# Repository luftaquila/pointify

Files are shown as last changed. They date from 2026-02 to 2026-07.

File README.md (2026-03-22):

# Pointify

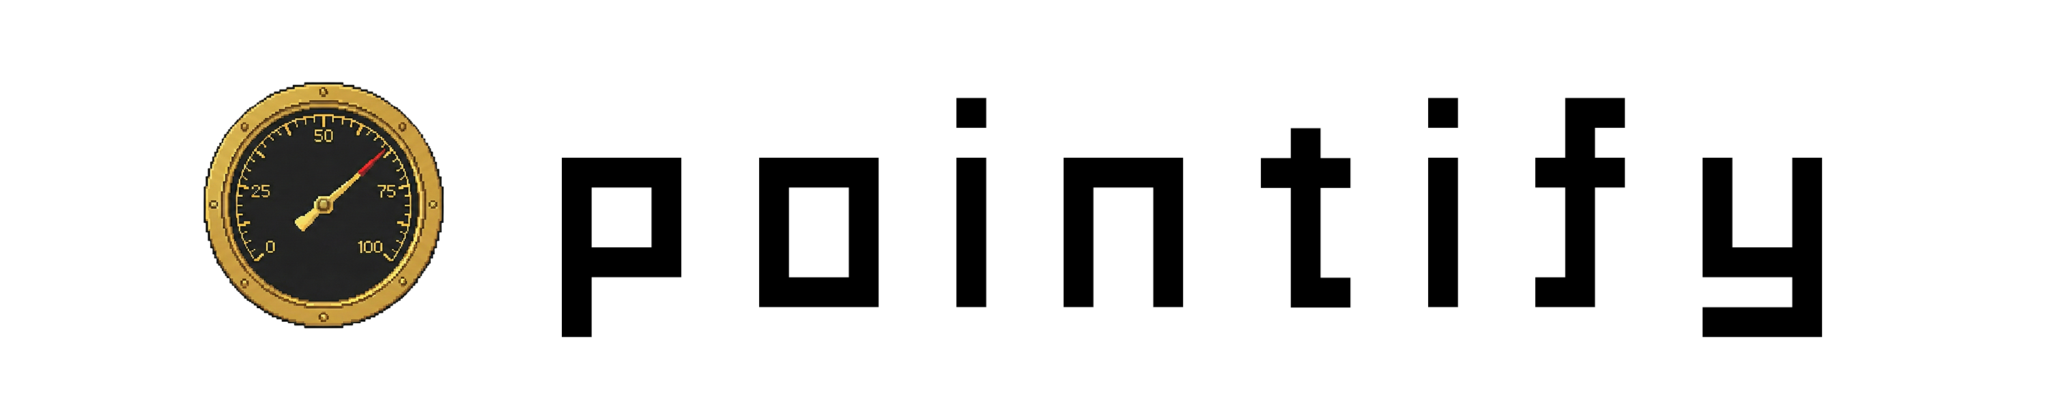
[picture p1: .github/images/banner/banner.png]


DIY retro analog gauge meters that display system metrics in real time, including Claude usage stats!

<table>
  <tr>
    <td>
      
    </td>
    <td>
      <video src="https://github.com/user-attachments/assets/7dd133b8-86af-4e1a-b1fe-1c4ecdfecce1" controls></video>
    </td>
  </tr>
</table>

## Usage

Pointify Desktop runs on macOS, Windows, and Linux, driving up to 8 gauges with customizable metrics.

Its software gauges work without the device, but watching real needles twitch is way better. So go build one!

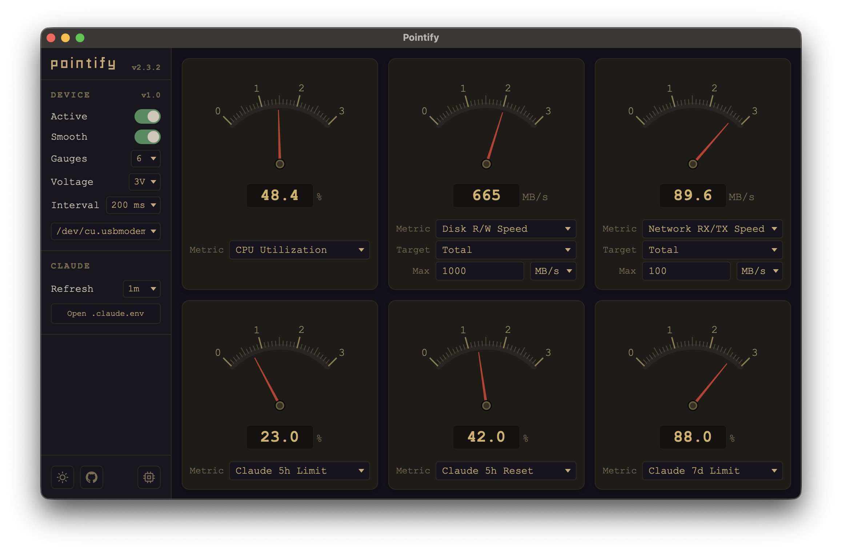
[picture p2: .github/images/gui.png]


1. Install Pointify Desktop and open it.
    * **macOS / Linux (Homebrew)**
      ```bash
      brew tap luftaquila/pointify https://github.com/luftaquila/pointify
      brew install --cask pointify # macOS
      brew install pointify        # Linux
      ```
    * **Windows (Manual)**: Download from the [latest release](https://github.com/luftaquila/pointify/releases/latest).
1. Connect your Pointify to the computer and set up gauges to your preference.

<details>

<summary>Full list of supported metrics</summary>

- 🕹️ Hardware
  - CPU
    - Utilization
    - Temperature
    - Clock Frequency
    - Power Consumption
  - GPU
    - Utilization
    - Temperature
    - Clock Frequency
    - Power Consumption
    - VRAM Usage
  - Memory
    - RAM and Swap Usage
  - Network
    - RX, TX and RX/TX Speed
  - Disk
    - Usage
    - Read, Write and R/W Speed
- **🤖 Claude Usage Stats**
  - Usage Limits
    - 5h session limit and reset time
    - Weekly limit and reset time
  - Claude Code stats
    - Today's total tokens
    - Today's input, output and I/O tokens
    - Today's cache read and write tokens
    - Today's cost ($)

</details>

> [!NOTE]
> Some metrics have platform/hardware limitations.
> * **CPU Temperature and Power**: Not available on Windows.
> * **GPU metrics**: Not supported on AMD graphics cards.
> * **GPU VRAM Usage**: Not available on Apple Silicon.

### Optional setup

To fetch Claude usage limits (5h session and weekly), Pointify needs your browser credentials.

Claude Code stats are collected from local logs and do not require credentials.

> [!NOTE]
> Credentials are stored locally and only used to fetch usage data directly from Claude. No information is sent to any third-party server.
> See the `get_claude_usage` function in [lib.rs](https://github.com/luftaquila/pointify/blob/v2/gui/src-tauri/src/lib.rs) for details.

<details>

<summary>Firefox</summary>

1. Open Firefox and visit `https://claude.ai`. Log in if you haven't already.
1. Open Developer Tools (F12).
1. Go to the `Storage` tab.
1. On the left sidebar, click `Cookies` - `https://claude.ai`.
1. Locate the `cf_clearance`, `lastActiveOrg`, and `sessionKey` values.
1. Click the `Open .claude.env` button on the desktop app and paste the corresponding values.

</details>

<details>

<summary>Chrome</summary>

1. Open Chrome and visit `https://claude.ai`. Log in if you haven't already.
1. Open Developer Tools (F12).
1. Go to the `Application` tab.
1. On the left sidebar, click `Storage` - `Cookies` - `https://claude.ai`.
1. Locate the `cf_clearance`, `lastActiveOrg`, and `sessionKey` values.
1. Click the `Open .claude.env` button on the desktop app and paste the corresponding values.

</details>

## Do It Yourself!

Pointify is fully open-source and open-hardware. Build your own device at home!

### 1. Build PCB

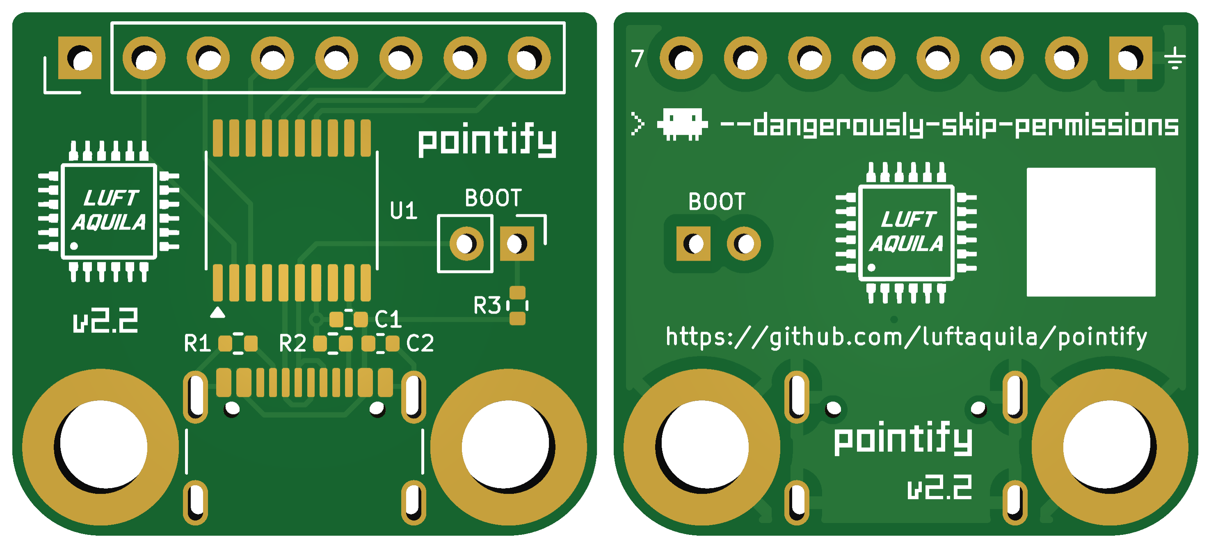
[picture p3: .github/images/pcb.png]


1. Download `pointify-hardware.zip` from the [latest release](https://github.com/luftaquila/pointify/releases/latest) and unzip.
1. Gerber, BOM, and CPL files are in the `pcb/` directory. Use them to place a PCB assembly order from manufacturers such as JLCPCB.

### 2. Upload Firmware

If your board is fresh and the MCU has never been flashed, it will always boot into USB bootloader mode.

1. Connect your board to the computer.
1. Open Pointify Desktop and click the chip icon at the bottom of the sidebar.

`CURRENT` version will show as `Bootloader`. Click the `Update Firmware` button to flash it.

> [!NOTE]
> If your computer is running Windows and `CURRENT` shows as `N/A`, it means the CH372 driver is missing.
> Press the `Shift` key and the button will change to `Update Firmware (force)`.
> The force install process will automatically detect and install the missing driver.
> Alternatively, you can install the driver manually from [here](https://www.wch-ic.com/downloads/CH372DRV_EXE.html).

### 3. 3D-Print Housing and Assembly

#### Prerequisites

* 6x M2*8mm bolts
* 91C4 3V DC analog voltmeters, as many as you need
* Some wires and soldering skills
* 4x anti-slip pads with radius < 10mm

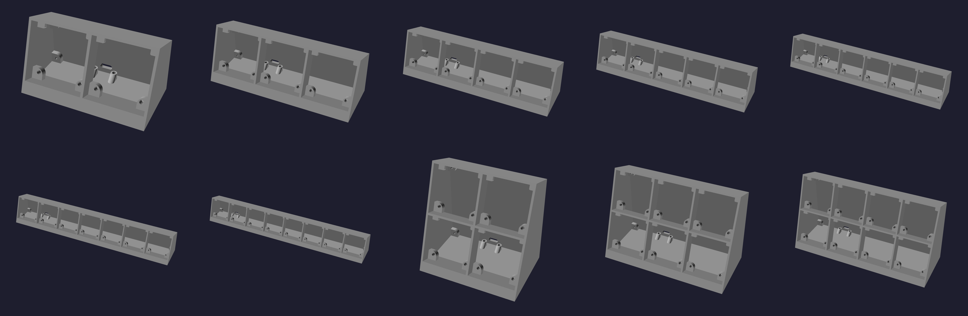
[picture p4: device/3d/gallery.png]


1. Download `pointify-hardware.zip` from the [latest release](https://github.com/luftaquila/pointify/releases/latest) and unzip.
1. 3D-print the STL files you need from the `3d/` directory.
1. Install the gauges into the housing.
1. Connect all negative terminals (near the 0V scale) of the gauge to the GND header on the PCB.
    * Daisy-chain them, since there's only one GND pad (marked ⏚).
1. Connect each positive terminal (near the 3V scale) to PWM port #1~8 on the PCB.
    * The pad right next to the GND is PWM1.
    * Solder directly to the washer that comes with the gauge, or crimp a ring terminal onto the wire. Crimping is easier to work with but you'll need a crimp tool and ring terminals.
1. Mount the PCB upside down onto the housing. The USB port faces downward.
1. Attach the back cover.

### 4. Customize Gauge Panel

Use the [Gauge Panel Generator](https://luftaquila.github.io/pointify/generator.html) to design and print your own gauge panel graphics.

Examples from the [device/gauge/example/](device/gauge/example) directory:

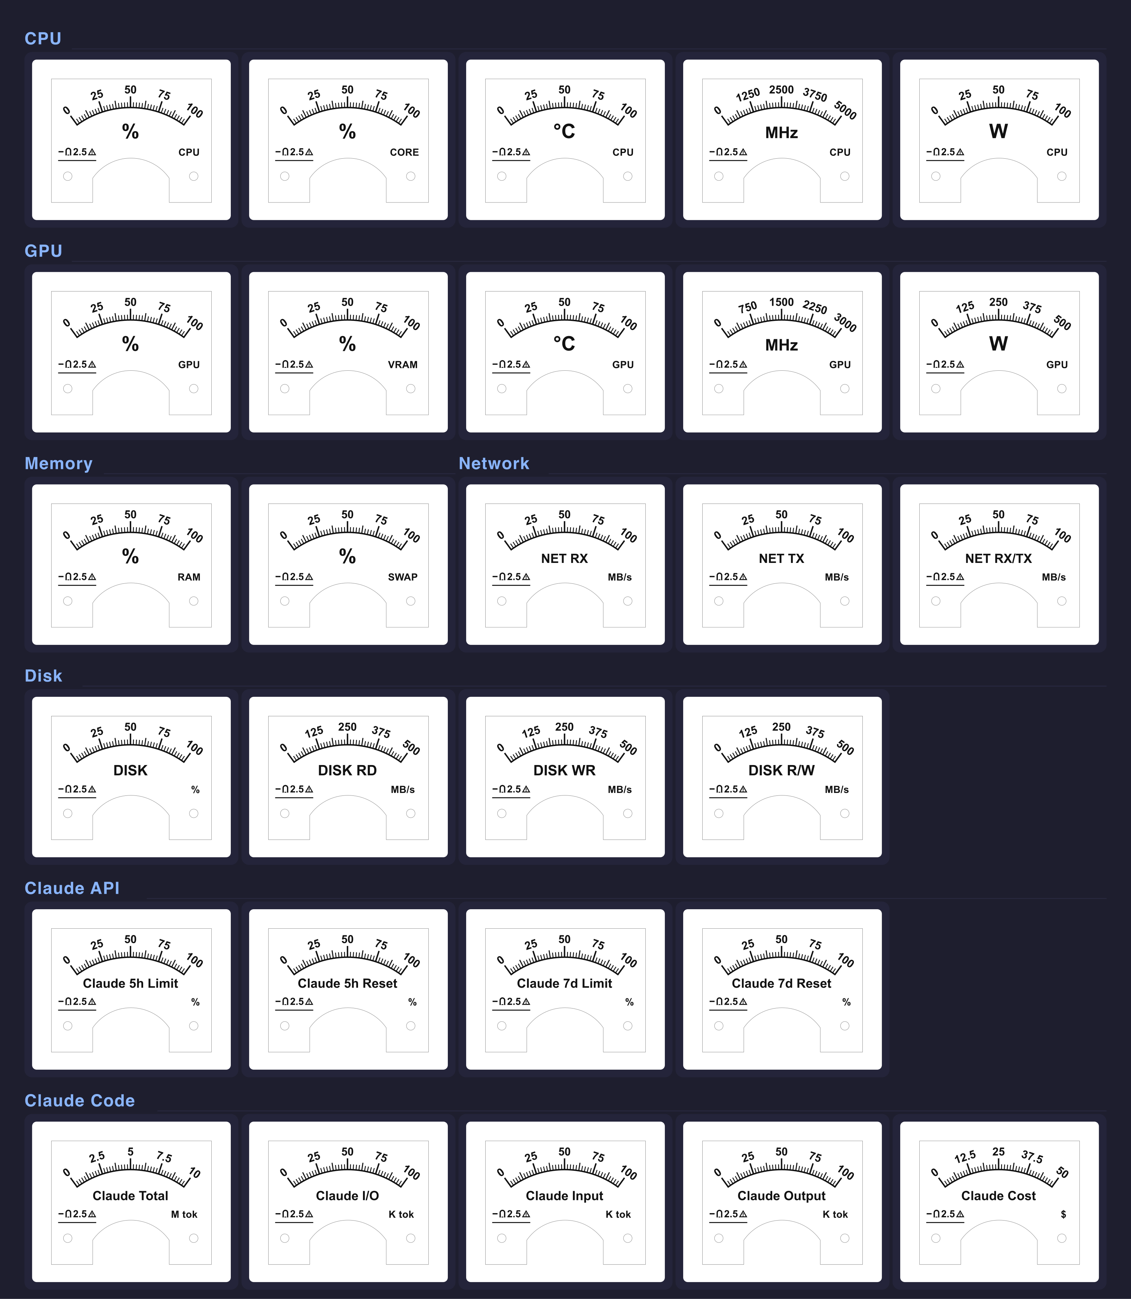
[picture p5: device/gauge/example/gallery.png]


## Development

<details>

<summary>Open</summary>

### Desktop App

Requires [Node.js](https://nodejs.org/en/download) and [Rust](https://rust-lang.org/tools/install/).

```bash
cd gui
npm install
npm run tauri dev       # development
npm run tauri build     # production
```

### Firmware

Requires [nightly Rust](https://rust-lang.github.io/rustup/concepts/channels.html#working-with-nightly-rust).

```bash
cargo install wchisp --git https://github.com/ch32-rs/wchisp

cd device/firmware
cargo build --release   # build only
cargo run --release     # build + flash
```

</details>

<hr>
<br>

<picture>
  <source media="(prefers-color-scheme: dark)" srcset="https://api.star-history.com/svg?repos=luftaquila/pointify&type=Date&theme=dark" />
  <source media="(prefers-color-scheme: light)" srcset="https://api.star-history.com/svg?repos=luftaquila/pointify&type=Date" />
  Star History Chart
</picture>

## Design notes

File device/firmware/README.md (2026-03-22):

# pointify-firmware

CH32X033F8P6 firmware built on [ch32-hal](https://github.com/ch32-rs/ch32-hal) with [Embassy](https://embassy.dev/) async runtime.

USB CDC ACM is implemented with raw PAC registers (`pac::usb::Usbd`) since ch32-hal has no USBFS HAL driver for this chip.

## Features

- USB CDC ACM device (VID=0x0200, PID=0x02DB)
- 8-channel PWM output (TIM1/TIM2/TIM3)
- Auto-detect 3.3V/5V supply via ADC internal reference
- Voltage-aware PWM scaling (3V gauges on 5V supply are scaled down)

## Prerequisites

```bash
cargo install probe-rs-tools
```

## Build & Flash

```bash
cargo run --release
```

Build only:

```bash
cargo build --release
```

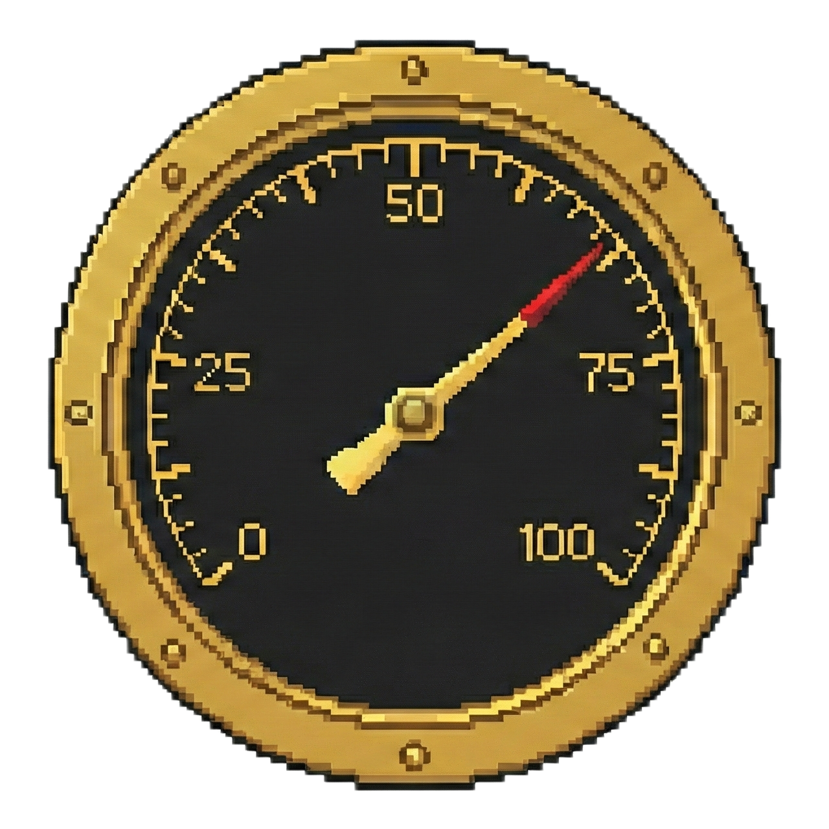
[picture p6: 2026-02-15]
.github/images/pointify.png

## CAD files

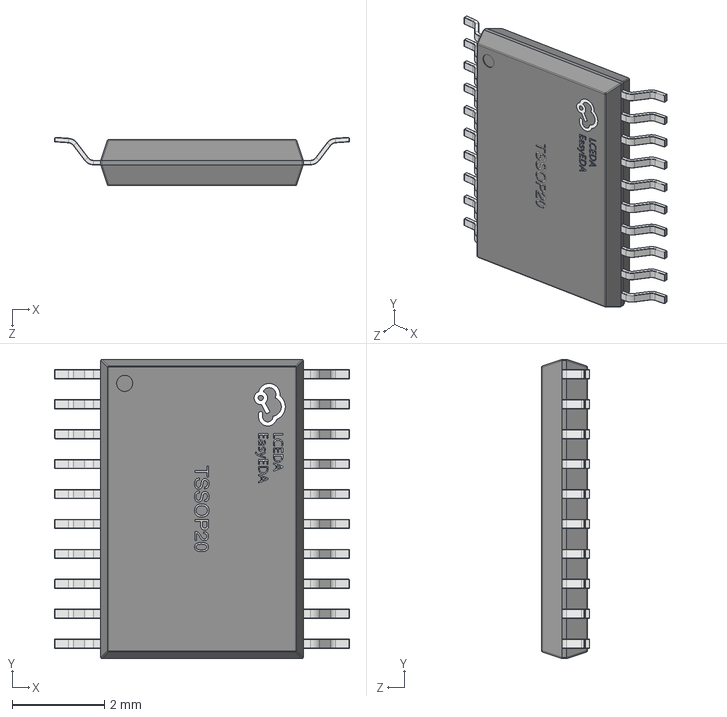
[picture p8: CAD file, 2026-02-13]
device/hardware/ch32x033f8p6/CH32X033F8P6.step
6.41 x 6.50 x 1.05 mm

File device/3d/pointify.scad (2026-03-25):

// ==========================================
// 1. Configuration & Parameters
// ==========================================
$fn = 100;

// [Grid Configuration]
num_cols = 3; // Columns (Width)
num_rows = 1; // Rows (Height)

// [Dimensions]
hole_sz = 46; // Unit hole size
hole_w = hole_sz - 1.0; // Hole width
hole_h = hole_sz - 0.5; // Hole height

gap = 2.0; // Wall thickness
margin_bot = 10; // Bottom margin
margin_top = 2.0; // Top margin

// [Calculated Dimensions]
// Total Width = (Cols * Hole) + Walls
face_w = (num_cols * hole_w) + ( (num_cols + 1) * gap);
// Total Height = (Rows * Hole) + Walls + Margins
face_h = margin_bot + (num_rows * hole_h) + ( (num_rows - 1) * gap) + margin_top;

// [View Settings]
explode_dist = 40; // 0 for assembly, >0 for exploded view
tolerance = 0.2;

// [Cover & Screw Settings]
cover_thickness = 3.0;
m2_tap_radius = 1.0; // Body hole (M2 Tap)
m2_clearance_radius = 1.5; // Cover hole (M2 Clearance)
m2_head_radius = 2.1; // Counterbore dia
m2_head_depth = 2.0; // Counterbore depth

// [Mounting Tab Settings]
tab_depth_len = 4;
tab_fillet_r = 4.0;

// [PCB & USB Settings]
pcb_hole_dist = 16.14;
pcb_dist_from_cover = 3.8;
pcb_boss_height = 5.0;
pcb_boss_dia = 5.0;
patch_nut_height = 2.0;

usb_w = 9.8;
usb_h = 3.8;
usb_r = usb_h / 2;

// [Geometry Definition]
tilt_angle = 20;
top_side_length = 32;
tab_depth = 9.5;
floor_thickness = 2.0;

// [Front Tab Settings]
hole_x = 6;
hole_z = 6;
target_diag_dist = 11;
tab_size_lower = 9.2;
tab_size_upper = tab_size_lower * 0.7;
tab_thick_lower = 5.0;
tab_thick_upper = 3.0;
hole_tap_radius = 1.7;

divider_cut_depth = tab_depth + tab_thick_lower;

// [Anti-slip Sticker Recess]
sticker_dia = 12.0;
sticker_depth = 1.0;
sticker_inset_x = 9;
sticker_inset_y = 9;

// ==========================================
// 2. Main Assembly
// ==========================================

union() {
  difference() {
    union() {
      // Main Body with Internal Cutouts
      difference() {
        shell_body();
        intersection() {
          rotated_holes_with_cut_dividers();
          translate([-50, -200, floor_thickness])
            cube([face_w + 100, 500, 300]);
        }
      }
      // Add Components
      rotated_tabs();
      rear_mounting_tabs_fixed_height();
      pcb_bosses_solid();
      pcb_boss_supports();
    }
    // Subtract PCB Screw Holes
    pcb_boss_holes();
    // Subtract Anti-slip Sticker Recesses
    sticker_recesses();
  }
}

// Back Cover (Positioned based on explode_dist)
translate([0, calc_back_cut_y() + explode_dist, 0])
  lip_insert_counterbored();

// ==========================================
// 3. Modules & Functions
// ==========================================

// Module: Back Cover with USB & Screw Holes
module lip_insert_counterbored() {
  y_cut = calc_back_cut_y();
  h_top_local = face_h - margin_top;
  h_bot_local = margin_bot;

  z_top_raw = ( -y_cut * tan(tilt_angle)) + (h_top_local / cos(tilt_angle));
  z_bot_raw = ( -y_cut * tan(tilt_angle)) + (h_bot_local / cos(tilt_angle));
  z_bot_actual = max(z_bot_raw, floor_thickness);
  lip_h = z_top_raw - z_bot_actual;

  inner_total_width = face_w - (2 * gap);
  margin_x = gap + 4;
  end_x = gap + inner_total_width;

  // Top Tabs Z reference
  h_tabs_top_local = face_h - margin_top;
  z_top_tabs = ( -y_cut * tan(tilt_angle)) + (h_tabs_top_local / cos(tilt_angle));

  z_top_hole = z_top_tabs - 4;
  z_bot_hole = z_bot_actual + 4;
  hole_coords = [[margin_x, z_top_hole], [end_x - 4, z_top_hole], [margin_x, z_bot_hole], [end_x - 4, z_bot_hole]];

  // USB Position Calculation
  div_center_x = gap + hole_w + (gap / 2);
  pcb_bottom_z = floor_thickness + pcb_boss_height + patch_nut_height;
  usb_center_z = pcb_bottom_z - 0.5; // USB connector center (fixed)

  difference() {
    // Main Lip Body
    color("#ffaa00")
      translate([gap + tolerance, -cover_thickness, z_bot_actual + tolerance])
        cube([inner_total_width - (2 * tolerance), cover_thickness, lip_h - (2 * tolerance)]);

    // Screw Holes
    for (pt = hole_coords) {
      translate([pt[0], 0, pt[1]]) rotate([90, 0, 0])
          union() {
            translate([0, 0, -1]) cylinder(r=m2_clearance_radius, h=cover_thickness + 5);
            translate([0, 0, -0.1]) cylinder(r=m2_head_radius, h=m2_head_depth + 0.1);
          }
    }

    // USB Type-C Cutout (Racetrack)
    translate([div_center_x, 1, usb_center_z])
      rotate([90, 0, 0])
        linear_extrude(height=cover_thickness + 5) {
          hull() {
            translate([-(usb_w / 2 - usb_r), 0]) circle(r=usb_r);
            translate([(usb_w / 2 - usb_r), 0]) circle(r=usb_r);
          }
        }
  }
}

// Module: PCB Mounting Bosses (Solid)
module pcb_bosses_solid() {
  y_cut = calc_back_cut_y();
  y_pos = y_cut - cover_thickness - pcb_dist_from_cover;
  div_center_x = gap + hole_w + (gap / 2);
  x_pos_left = div_center_x - (pcb_hole_dist / 2);
  x_pos_right = div_center_x + (pcb_hole_dist / 2);

  translate([0, 0, floor_thickness]) {
    translate([x_pos_left, y_pos, 0]) cylinder(d=pcb_boss_dia, h=pcb_boss_height);
    translate([x_pos_right, y_pos, 0]) cylinder(d=pcb_boss_dia, h=pcb_boss_height);
  }
}

// Module: PCB Boss Print Supports (45° ramp on -Y overhang side for face-down printing)
module pcb_boss_supports() {
  y_cut = calc_back_cut_y();
  y_pos = y_cut - cover_thickness - pcb_dist_from_cover;
  div_center_x = gap + hole_w + (gap / 2);
  x_pos_left = div_center_x - (pcb_hole_dist / 2);
  x_pos_right = div_center_x + (pcb_hole_dist / 2);

  for (x = [x_pos_left, x_pos_right]) {
    hull() {
      translate([x, y_pos, floor_thickness + pcb_boss_height - 0.01])
        cylinder(d=pcb_boss_dia, h=0.01);
      translate([x, y_pos, floor_thickness])
        cylinder(d=pcb_boss_dia, h=0.01);
      translate([x, y_pos - pcb_boss_height, floor_thickness])
        cylinder(d=pcb_boss_dia, h=0.01);
    }
  }
}

// Module: PCB Mounting Holes (Counterbored)
module pcb_boss_holes() {
  y_cut = calc_back_cut_y();
  y_pos = y_cut - cover_thickness - pcb_dist_from_cover;
  div_center_x = gap + hole_w + (gap / 2);
  x_pos_left = div_center_x - (pcb_hole_dist / 2);
  x_pos_right = div_center_x + (pcb_hole_dist / 2);

  for (x = [x_pos_left, x_pos_right]) {
    translate([x, y_pos, -0.1]) {
      union() {
        cylinder(r=m2_head_radius, h=floor_thickness + 0.1);
        translate([0, 0, floor_thickness]) cylinder(r=m2_clearance_radius, h=pcb_boss_height + 10);
      }
    }
  }
}

// Module: Rear Mounting Tabs (Auto-sizing)
module rear_mounting_tabs_fixed_height() {
  y_cut = calc_back_cut_y();
  h_top_local = face_h - margin_top;
  h_bot_local = margin_bot;

  z_top_global = ( -y_cut * tan(tilt_angle)) + (h_top_local / cos(tilt_angle));
  z_bot_raw = ( -y_cut * tan(tilt_angle)) + (h_bot_local / cos(tilt_angle));
  z_bot_global = max(z_bot_raw, floor_thickness);

  inner_total_width = face_w - (2 * gap);
  start_x = gap;
  end_x = gap + inner_total_width;

  tab_w = 8;
  tab_h = 8;
  margin_x = gap + 4;

  z_top_hole = z_top_global - 4;
  z_bot_hole = z_bot_global + 4;
  hole_coords = [[margin_x, z_top_hole], [end_x - 4, z_top_hole], [margin_x, z_bot_hole], [end_x - 4, z_bot_hole]];

  translate([0, y_cut, 0]) difference() {
      union() {
        // Bottom Tabs
        translate([start_x, -cover_thickness - tab_depth_len, z_bot_global])
          block_y_fillet_top(tab_w, tab_depth_len, tab_h, tab_fillet_r);
        translate([end_x, -cover_thickness - tab_depth_len, z_bot_global])
          mirror([1, 0, 0]) block_y_fillet_top(tab_w, tab_depth_len, tab_h, tab_fillet_r);

        // Top Tabs (Intersect with Ceiling)
        intersection() {
          union() {
            fixed_bottom_z = z_top_global - tab_h;
            translate([start_x, -cover_thickness - tab_depth_len, fixed_bottom_z])
              block_y_fillet_bottom(tab_w, tab_depth_len, tab_h + 15, tab_fillet_r);
            translate([end_x, -cover_thickness - tab_depth_len, fixed_bottom_z])
              mirror([1, 0, 0]) block_y_fillet_bottom(tab_w, tab_depth_len, tab_h + 15, tab_fillet_r);
          }
          translate([0, -y_cut, 0]) rotate([-tilt_angle, 0, 0])
              translate([-100, -200, -100]) cube([face_w + 100, 500, 100 + face_h]);
        }
      }
      // Screw Holes
      for (pt = hole_coords) {
        translate([pt[0], -cover_thickness + 1, pt[1]]) rotate([90, 0, 0])
            cylinder(r=m2_tap_radius, h=tab_depth_len + 5);
      }
    }
}
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

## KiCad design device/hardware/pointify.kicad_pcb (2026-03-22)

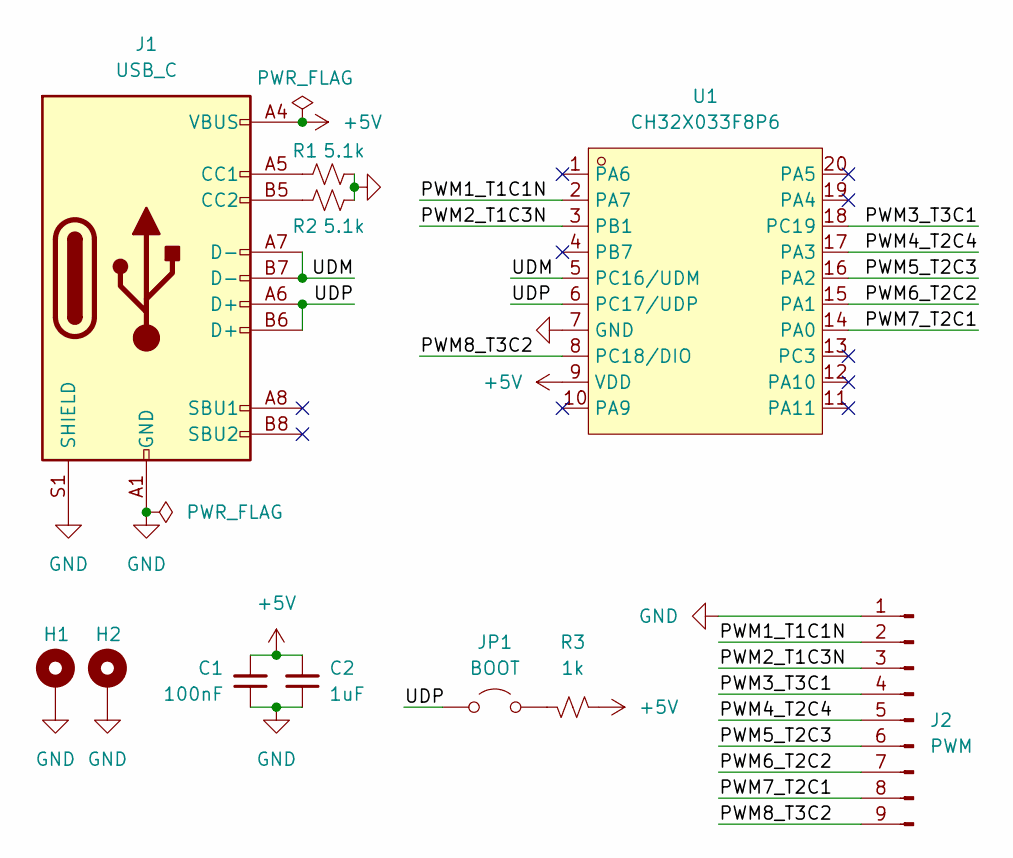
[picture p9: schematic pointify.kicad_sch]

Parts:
C1: 100nF; C_0402_1005Metric; LCSC C1525
C2: 1uF; C_0402_1005Metric; LCSC C52923
H1, H2: MountingHole_Pad; MountingHole_3.7mm_Pad_TopBottom; LCSC C2916384
J1: USB_C; USB_C_Receptacle_GCT_USB4105-xx-A_16P_TopMnt_Horizontal; LCSC C2927038
J2: PWM; PinHeader_1x09_P2.54mm_Vertical
JP1: BOOT; PinHeader_1x02_P2.00mm_Vertical
R1, R2: 5.1k; R_0402_1005Metric; LCSC C25905
R3: 1k; R_0402_1005Metric; LCSC C11702
U1: CH32X033F8P6; TSSOP-20_4.4x6.5mm_P0.65mm; LCSC Part C19268290

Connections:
+5V: C1.2, C2.2, J1.A4 (VBUS), J1.A9 (VBUS), J1.B4 (VBUS), J1.B9 (VBUS), R3.1, U1.9 (VDD)
/PWM1_T1C1N: J2.2, U1.2 (PA7)
/PWM2_T1C3N: J2.3, U1.3 (PB1)
/PWM3_T3C1: J2.4, U1.18 (PC19)
/PWM4_T2C4: J2.5, U1.17 (PA3)
/PWM5_T2C3: J2.6, U1.16 (PA2)
/PWM6_T2C2: J2.7, U1.15 (PA1)
/PWM7_T2C1: J2.8, U1.14 (PA0)
/PWM8_T3C2: J2.9, U1.8 (PC18/DIO)
/UDM: J1.A7 (D-), J1.B7 (D-), U1.5 (PC16/UDM)
/UDP: J1.A6 (D+), J1.B6 (D+), JP1.2 (B), U1.6 (PC17/UDP)
GND: C1.1, C2.1, H1.1, H2.1, J1.A1 (GND), J1.A12 (GND), J1.B1 (GND), J1.B12 (GND), J1.S1 (SHIELD), J2.1, R1.2, R2.2, U1.7 (GND)
unnamed: J1.A5 (CC1), R1.1
unnamed: J1.B5 (CC2), R2.1
unnamed: JP1.1 (A), R3.2

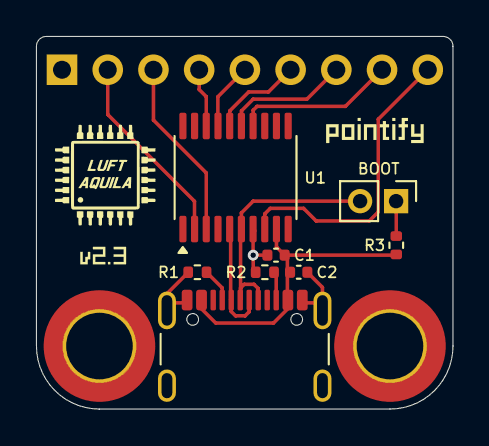
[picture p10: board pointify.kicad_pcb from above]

Board: 2 copper layers, 23.1 x 20.7 mm, 11 parts (0 on the bottom side), 15 nets.

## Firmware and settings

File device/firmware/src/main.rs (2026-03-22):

#![no_std]
#![no_main]
#![feature(type_alias_impl_trait)]
#![feature(impl_trait_in_assoc_type)]

mod usb_cdc;

use ch32_hal as hal;
use embassy_executor::Spawner;
use hal::adc::{Adc, SampleTime, VrefInt};
use hal::time::Hertz;
use hal::timer::complementary_pwm::{ComplementaryPwm, ComplementaryPwmPin};
use hal::timer::low_level::CountingMode;
use hal::timer::simple_pwm::{PwmPin, SimplePwm};
use hal::timer::Channel;

#[embassy_executor::main(entry = "qingke_rt::entry")]
async fn main(_spawner: Spawner) -> ! {
    let mut config = hal::Config::default();
    config.rcc = hal::rcc::Config::SYSCLK_FREQ_48MHZ_HSI;
    let p = hal::init(config);

    // ADC
    let mut adc = Adc::new(p.ADC1, Default::default());
    let mut vrefint = VrefInt;
    let vref_raw = adc.convert(&mut vrefint, SampleTime::CYCLES11) as u32;
    let is_5v_supply = vref_raw < 1200;

    // TIM2 remap=0: PA0, PA1, PA2, PA3
    let ch1 = PwmPin::new_ch1::<0>(p.PA0);
    let ch2 = PwmPin::new_ch2::<0>(p.PA1);
    let ch3 = PwmPin::new_ch3::<0>(p.PA2);
    let ch4 = PwmPin::new_ch4::<0>(p.PA3);
    let mut pwm_tim2 = SimplePwm::new(
        p.TIM2, Some(ch1), Some(ch2), Some(ch3), Some(ch4),
        Hertz::khz(1), CountingMode::default(),
    );
    pwm_tim2.enable(Channel::Ch1);
    pwm_tim2.enable(Channel::Ch2);
    pwm_tim2.enable(Channel::Ch3);
    pwm_tim2.enable(Channel::Ch4);

    // Release PC18/DIO and PC19/DCK debug pins for GPIO/timer use
    // AFIO_PCFR1 bits[26:24] = sw_cfg = 0b100 (disable debug, release both pins)
    unsafe {
        let afio_pcfr1 = 0x4001_0004 as *mut u32;
        let val = afio_pcfr1.read_volatile();
        afio_pcfr1.write_volatile((val & !(0x07 << 24)) | (0x04 << 24));
    }

    // TIM3 remap=2: PC19(CH1), PC18(CH2)
    let ch1_t3 = PwmPin::new_ch1::<2>(p.PC19);
    let ch2_t3 = PwmPin::new_ch2::<2>(p.PC18);
    let mut pwm_tim3 = SimplePwm::new(
        p.TIM3, Some(ch1_t3), Some(ch2_t3), None, None,
        Hertz::khz(1), CountingMode::default(),
    );
    pwm_tim3.enable(Channel::Ch1);
    pwm_tim3.enable(Channel::Ch2);

    // TIM1 remap=1: PA7(CH1N), PB1(CH3N)
    let ch1n = ComplementaryPwmPin::new_ch1::<1>(p.PA7);
    let ch3n = ComplementaryPwmPin::new_ch3::<1>(p.PB1);
    let mut pwm_tim1 = ComplementaryPwm::new(
        p.TIM1, None, Some(ch1n), None, None, None, Some(ch3n), None,
        Hertz::khz(1), CountingMode::default(),
    );
    pwm_tim1.set_dead_time(0);
    pwm_tim1.enable(Channel::Ch1);
    pwm_tim1.enable(Channel::Ch3);

    // HAL ComplementaryPwm doesn't work properly with N-only channels.
    // Configure TIM1 entirely via raw registers.
    const TIM1: usize = 0x4001_2C00;
    unsafe {
        // CR1: CEN (bit 0) = 1 — start counter
        let cr1 = (TIM1 + 0x00) as *mut u32;
        let v = cr1.read_volatile();
        cr1.write_volatile(v | 1);
        // CCMR1: OC1M = PWM mode 2 (0b111), OC1PE = 1
        let ccmr1 = (TIM1 + 0x18) as *mut u32;
        let v = ccmr1.read_volatile();
        ccmr1.write_volatile((v & !(0x7 << 4)) | (0x7 << 4) | (1 << 3));
        // CCMR2: OC3M = PWM mode 2 (0b111), OC3PE = 1
        let ccmr2 = (TIM1 + 0x1C) as *mut u32;
        let v = ccmr2.read_volatile();
        ccmr2.write_volatile((v & !(0x7 << 4)) | (0x7 << 4) | (1 << 3));
        // CCER: CC1NE (bit 2) = 1, CC3NE (bit 10) = 1
        let ccer = (TIM1 + 0x20) as *mut u32;
        let v = ccer.read_volatile();
        ccer.write_volatile(v | (1 << 2) | (1 << 10));
        // BDTR: MOE (bit 15) = 1
        let bdtr = (TIM1 + 0x44) as *mut u32;
        let v = bdtr.read_volatile();
        bdtr.write_volatile(v | (1 << 15));
    }

    usb_cdc::usb_init();

    let max_duty_tim2 = pwm_tim2.get_max_duty();
    let max_duty_tim3 = pwm_tim3.get_max_duty();
    let max_duty_tim1 = unsafe { ((TIM1 + 0x2C) as *const u32).read_volatile() as u16 }; // ARR

    let mut rx_buf = [0u8; 64];
    loop {
        if let Some(len) = usb_cdc::usb_poll(&mut rx_buf) {
            for chunk in rx_buf[..len].chunks_exact(2) {
                let raw = u16::from_be_bytes([chunk[0], chunk[1]]);
                let is_5v_gauge = (raw & 0x8000) != 0;
                let index = ((raw >> 10) & 0x1F) as u8;
                let value = raw & 0x3FF;
                let scale_3v = is_5v_supply && !is_5v_gauge;

                match index {
                    0 => unsafe { ((TIM1 + 0x34) as *mut u32).write_volatile(duty_u16(value, max_duty_tim1, scale_3v) as u32) }, // CCR1 (PA7)
                    1 => unsafe { ((TIM1 + 0x3C) as *mut u32).write_volatile(duty_u16(value, max_duty_tim1, scale_3v) as u32) }, // CCR3 (PB1)
                    2 => pwm_tim3.set_duty(Channel::Ch1, duty_u32(value, max_duty_tim3, scale_3v)),
                    7 => pwm_tim3.set_duty(Channel::Ch2, duty_u32(value, max_duty_tim3, scale_3v)),
                    3 => pwm_tim2.set_duty(Channel::Ch4, duty_u32(value, max_duty_tim2, scale_3v)),
                    4 => pwm_tim2.set_duty(Channel::Ch3, duty_u32(value, max_duty_tim2, scale_3v)),
                    5 => pwm_tim2.set_duty(Channel::Ch2, duty_u32(value, max_duty_tim2, scale_3v)),
                    6 => pwm_tim2.set_duty(Channel::Ch1, duty_u32(value, max_duty_tim2, scale_3v)),
                    31 if value == 0x3FF => {
                        // Zero all PWMs as visual confirmation before bootloader
                        pwm_tim2.set_duty(Channel::Ch1, 0);
                        pwm_tim2.set_duty(Channel::Ch2, 0);
                        pwm_tim2.set_duty(Channel::Ch3, 0);
                        pwm_tim2.set_duty(Channel::Ch4, 0);
                        pwm_tim3.set_duty(Channel::Ch1, 0);
                        pwm_tim3.set_duty(Channel::Ch2, 0);
                        unsafe { ((TIM1 + 0x34) as *mut u32).write_volatile(0) }; // CCR1
                        unsafe { ((TIM1 + 0x3C) as *mut u32).write_volatile(0) }; // CCR3
                        usb_cdc::enter_bootloader();
                    }
                    _ => {}
                }
            }
        }
    }
}

fn duty_u32(value: u16, max_duty: u32, scale_3v: bool) -> u32 {
    if scale_3v {
        (value as u32 * max_duty * 3) / (1023 * 5)
    } else {
        (value as u32 * max_duty) / 1023
    }
}

fn duty_u16(value: u16, max_duty: u16, scale_3v: bool) -> u16 {
    if scale_3v {
        ((value as u32 * max_duty as u32 * 3) / (1023 * 5)) as u16
    } else {
        ((value as u32 * max_duty as u32) / 1023) as u16
    }
}

#[panic_handler]
fn panic(_info: &core::panic::PanicInfo) -> ! {
    loop {}
}

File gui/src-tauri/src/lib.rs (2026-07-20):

mod claude;
mod codex;
mod credentials;
mod flasher;
mod monitor;
mod serial_loop;

use std::collections::HashMap;
use std::fs;
use std::io::Write;
use std::path::PathBuf;
use std::sync::atomic::{AtomicU64, Ordering};
use std::sync::{Arc, Mutex};
use std::time::{Duration, SystemTime, UNIX_EPOCH};

use serde::{Deserialize, Serialize};
use tauri::{
    image::Image,
    menu::{CheckMenuItem, Menu, MenuItem, PredefinedMenuItem},
    tray::{MouseButton, MouseButtonState, TrayIconBuilder, TrayIconEvent},
    webview::WebviewWindow,
    Emitter, Manager, State, WindowEvent,
};

use nusb::MaybeFuture;
use tauri_plugin_autostart::ManagerExt;

use claude::{AccountInfo, ClaudeCache, ClaudeTtl, ClaudeUsageEntry, SharedClaudeCodeStats};
use codex::{CodexAccount, CodexCache, CodexIdentity, CodexStatus, CodexStatusState, CodexUsage};
use credentials::{ClaudeAccount, SharedCredentials};
use monitor::types::SystemMetrics;
use monitor::{SharedInterval, SharedMetrics};
use serial_loop::{SerialConfig, SharedSerialConfig};

type SharedSerial = Arc<Mutex<Option<Box<dyn serialport::SerialPort + Send>>>>;

/// Show window and nudge its size to force macOS WKWebView to re-render.
/// Without this, the WebView can blank out after a hide/show cycle.
fn show_window(window: &WebviewWindow) {
    let _ = window.show();
    let _ = window.set_focus();
    if let Ok(size) = window.inner_size() {
        let _ = window.set_size(tauri::Size::Physical(tauri::PhysicalSize {
            width: size.width + 1,
            height: size.height,
        }));
        let _ = window.set_size(tauri::Size::Physical(size));
    }
}

/// Monotonic ms timestamp for heartbeat liveness checks.
fn now_ms() -> u64 {
    SystemTime::now()
        .duration_since(UNIX_EPOCH)
        .map(|d| d.as_millis() as u64)
        .unwrap_or(0)
}

/// Tracks the last time the frontend reported it was alive.
/// Seeded at startup so the watchdog doesn't fire before the page loads.
static LAST_HEARTBEAT_MS: AtomicU64 = AtomicU64::new(0);

/// Reload the WebView when JS stops sending heartbeats.
/// After days of idle on macOS the WKWebView WebContent process can die,
/// leaving a blank window that no amount of forceRepaint can recover —
/// only a full reload brings it back.
fn start_heartbeat_watchdog(app: tauri::AppHandle) {
    LAST_HEARTBEAT_MS.store(now_ms(), Ordering::Relaxed);
    std::thread::spawn(move || {
        // Grace period before first check: let the page load
        std::thread::sleep(Duration::from_secs(30));
        loop {
            std::thread::sleep(Duration::from_secs(15));
            let age = now_ms().saturating_sub(LAST_HEARTBEAT_MS.load(Ordering::Relaxed));
            if age > 60_000 {
                if let Some(window) = app.get_webview_window("main") {
                    eprintln!("Heartbeat stale ({}ms), reloading WebView", age);
                    LAST_HEARTBEAT_MS.store(now_ms(), Ordering::Relaxed);
                    // Native reload via wry dispatcher — works even when the
                    // WebContent process has died, which is exactly the case
                    // where window.eval(...) silently no-ops.
                    let _ = window.reload();
                }
            }
        }
    });
}

#[derive(Serialize)]
struct MetricOptions {
    cpu_core_count: usize,
    network_interfaces: Vec<String>,
    disk_names: Vec<String>,
    gpu_count: usize,
    gpu_names: Vec<String>,
}

#[derive(Serialize, Deserialize, Clone)]
#[serde(rename_all = "camelCase")]
struct GaugeConfig {
    metric_id: String,
    sub_index: String,
    #[serde(default)]
    account_id: Option<String>,
    #[serde(default)]
    org_id: Option<String>,
    max_value: Option<f64>,
    max_unit: Option<String>,
}

#[derive(Serialize, Deserialize, Clone)]
#[serde(rename_all = "camelCase")]
struct Config {
    active: bool,
    #[serde(default = "default_voltage")]
    voltage: String,
    interval_ms: u64,
    gauge_count: usize,
    #[serde(default = "default_rows")]
    rows: usize,
    #[serde(default = "default_cols")]
    cols: usize,
    gauges: Vec<GaugeConfig>,
    #[serde(default = "default_claude_refresh")]
    claude_refresh_secs: u64,
    #[serde(default)]
    smooth: bool,
    #[serde(default)]
    overshoot: bool,
    theme: String,
}

fn default_voltage() -> String {
    "3".to_string()
}
fn default_claude_refresh() -> u64 {
    120
}
fn default_rows() -> usize {
    1
}
fn default_cols() -> usize {
    3
}

#[tauri::command]
fn get_metrics(state: State<SharedMetrics>) -> Option<SystemMetrics> {
    state.lock().ok().and_then(|lock| lock.clone())
}

#[tauri::command]
fn set_interval(interval: State<SharedInterval>, ms: u64) {
    interval.store(ms, Ordering::Relaxed);
}

#[tauri::command]
fn update_serial_config(
    config: SerialConfig,
    serial_config: State<SharedSerialConfig>,
    interval: State<SharedInterval>,
) {
    interval.store(config.interval_ms, Ordering::Relaxed);
    if let Ok(mut lock) = serial_config.lock() {
        if lock.active && !config.active {
            serial_loop::request_send_zeros();
        }
        *lock = config;
    }
}

#[tauri::command]
fn load_config(app: tauri::AppHandle) -> Option<Config> {
    let path = app.path().app_config_dir().ok()?.join("config.json");
    let data = fs::read_to_string(path).ok()?;
    serde_json::from_str(&data).ok()
}

#[tauri::command]
fn save_config(app: tauri::AppHandle, config: Config) {
    if let Ok(dir) = app.path().app_config_dir() {
        let _ = fs::create_dir_all(&dir);
        if let Ok(json) = serde_json::to_string_pretty(&config) {
            let _ = fs::write(dir.join("config.json"), json);
        }
    }
}

#[derive(Serialize, Clone)]
struct SerialPortInfo {
    port: String,
    product: String,
}

#[tauri::command]
fn list_serial_ports() -> Vec<SerialPortInfo> {
    serialport::available_ports()
        .unwrap_or_default()
        .into_iter()
        .filter_map(|p| {
            if let serialport::SerialPortType::UsbPort(usb) = &p.port_type {
                if !(usb.vid == 512 && usb.pid == 731) {
                    return None;
                }
                // On macOS, prefer /dev/cu.* over /dev/tty.* for reliable flush-on-close
                #[cfg(target_os = "macos")]
                if p.port_name.contains("/dev/tty.") {
                    return None;
                }
                return Some(SerialPortInfo {
                    port: p.port_name,
                    product: usb.product.clone().unwrap_or_default(),
                });
            }
            None
        })
        .collect()
}

#[tauri::command]
fn set_claude_ttl(ttl: State<'_, ClaudeTtl>, secs: u64) {
    ttl.0.store(secs, Ordering::Relaxed);
}
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

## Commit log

2026-02-09 fix: open text on macos
    [lib.rs]
2026-02-13 add: v2 pcb
    [CH32X033F8P6.step, pointify.kicad_pcb, pointify.kicad_sch]
2026-02-13 pcb v2.1: fix pinmaps
    [pointify.kicad_pcb, pointify.kicad_sch]
2026-02-13 update: translate font to polygons
    [pointify.kicad_pcb]
2026-02-14 add: CPU Power metric
2026-02-14 add: release workflows
    [pointify.kicad_sch]
2026-02-16 add: openscad 3d housing
    [pointify.scad]
2026-02-17 fix: gauge m3 bolt clearance hole diameter
    [pointify.scad]
2026-02-17 update: format scad
    [pointify.scad]
2026-02-18 fix: adjust gauge angle and tolerance
    [pointify.scad]
2026-02-18 add: anti-slip sticker placeholder
    [pointify.scad]
2026-02-19 fix: screw tab distance
    [pointify.scad]
2026-02-26 fix: rewrite USB CDC driver with raw registers for CH32X033 compatibility
    The ch32-hal PAC wrapper produced incorrect register values for the
    CH32X033 USBFS peripheral. Rewrote usb_cdc.rs to use direct register
    access, fixing multiple hardware quirks discovered during debugging:
    - Fix PID token values (OUT=0, IN=2, SETUP=3) matching WCH SDK
    - Remove RESET_SIE which prevented enumeration on CH32X033
    - Skip RX_LEN check for SETUP (CH32X033 returns incorrect values)
    - Dispatch on token only, ignoring ep field (reports ep=2 for EP0 SETUP)
    - Add compiler fences between DMA buffer writes and register access
    - Configure AFIO CTLR for USB PHY (1.5K pull-up, 3.3V LDO, USB_IOEN)
    - Explicitly enable A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
    [main.rs]
2026-02-26 fix: release PC19/DCK debug pin for TIM3 PWM output
    PC19 is shared with DCK (debug clock) on CH32X033F8P6. The pin
    defaults to debug function after reset, preventing GPIO/timer use.
    Set AFIO_PCFR1 sw_cfg=0b100 to disable debug and release PC19
    for TIM3_CH1 PWM output.
    [main.rs]
2026-02-26 improve: device detection
2026-02-26 update: fine-tune 3d model
    [pointify.scad]
2026-02-26 update: pcb v2.2
    [pointify.kicad_pcb, pointify.kicad_sch, pointify.scad]
2026-03-04 feat: reset all gauges to zero on deactivate and quit
    - Frontend: send PWM=0 for all gauges when active toggle is turned off
    - Backend: send PWM=0 for gauge indices 0-6 before app.exit on tray quit
    [lib.rs]
2026-03-04 update: reorganize sidebar layout
    - Remove Gauges section, move gauge count into Device section
    - Move Enter Bootloader button to sidebar footer with CPU icon
2026-03-04 update: replace title with SVG logo and show git version tag
    - Replace h1 text with Millenium BMP08 pixel font SVG logo
    - Add get_version Tauri command using git tag from build script
    - Display version tag right-aligned next to the logo
    [lib.rs]
2026-03-04 feat: display firmware version from USB bcdDevice descriptor in sidebar
    Read bcdDevice via nusb and decode BCD to show vMAJOR.MINOR next to the
    Device section header. Clears on disconnect.
2026-03-04 update: release workflow firmware artifact naming and AI changelog
    Parse bcdDevice from usb_cdc.rs to name firmware artifact as
    pointify-firmware-vX.Y.elf. Add hardware artifact packaging and
    Gemini-powered AI changelog generation for releases.
2026-03-04 update: add CI caching and rename hardware artifact folder
    - Add Swatinem/rust-cache for firmware and GUI Rust builds
    - Add npm cache via actions/setup-node cache option
    - Replace KiCad PPA install with cached Docker image (kicad/kicad:9.0)
    - Rename hardware artifact folder from hardware/ to pointify-hardware/
2026-03-04 feat: add smooth toggle for EMA-based PWM smoothing
    Adds a Smooth toggle in the sidebar (below Active) that applies
    exponential moving average smoothing to serial PWM output, preventing
    physical gauge needles from slamming against stops on rapid value changes.
    [lib.rs]
2026-03-04 fix: prevent firmware update with stale cached release info
    - Remove cache fallback in firmware modal: if GitHub fetch fails (e.g.
    deleted release), latestFwInfo becomes null and update button is
    disabled instead of showing stale cached version
    - Split download_and_flash into download_firmware + flash_firmware so
    download happens before bootloader entry; if download fails, device
    stays in normal mode and flash is never erased
    - Add .error_for_status() to catch HTTP 404 from deleted release assets
    - Add empty response check for downloaded firmware bytes
    [lib.rs]
2026-03-04 fix: reconnect device and refresh modal after firmware update
    Wait for device USB re-enumeration after flash reset, then refresh
    serial ports (which auto-selects the port and updates modal buttons)
    before restarting polling.
2026-03-04 feat: detect WCH bootloader and allow firmware update without serial port
    Add is_in_bootloader command to detect WCH bootloader USB devices
    (VID 4348/1a86, PID 55e0). Watch bootloader connect/disconnect via
    hotplug so the firmware modal updates automatically. When the device
    is already in bootloader mode, skip serial port requirement and
    bootloader entry step.
    [lib.rs]
2026-03-04 feat: modifier key functions for firmware update buttons
    Replace Enter Bootloader button with modifier keys on Update Firmware
    button: Alt/Option shows "Enter Bootloader", Shift shows "Update
    Firmware (force)". Detect WCH bootloader USB devices via hotplug so
    the modal updates automatically when the device enters bootloader
    mode, allowing firmware update without a serial port connection.
2026-03-04 fix: warm CI caches on main branch pushes for tag-triggered releases
    GitHub Actions caches are scoped by branch/tag — caches saved on a
    tag ref are not accessible from other tags, only default branch caches
    are. Add main branch push trigger so firmware, GUI, and PCB build jobs
    run on main pushes to warm caches. Housing job skipped on non-tag
    pushes since it has no caching.
2026-03-04 feat: add autostart support with tray menu toggle
    Replace "Hide Window" tray menu item with "Start on Login" checkbox
    using tauri-plugin-autostart. Uses LaunchAgent on macOS.
    [lib.rs]
2026-03-04 feat: auto-install WCH driver on Windows for firmware flashing
    Wait for bootloader device via hotplug after entering bootloader mode.
    If not detected within 3s, download and run the WCH driver installer,
    then wait again for the device to appear.
2026-03-04 fix: disable firmware update button when no device is connected
    Also update noDevice flag on hotplug events and wait for bootloader
    device via hotplug instead of fixed delay after entering bootloader.
2026-03-04 update: rename Installation to Notes in release and add Linux udev rules
    Add udev rules instructions for WCH bootloader USB device access
    required for firmware updates on Linux.
2026-03-05 add: 3d housing gallery
2026-03-09 fix: move serial polling loop to Rust backend to prevent background throttling
    WebView throttles the main thread event loop when the window is hidden,
    which stops gauge updates even with Web Worker timers. Move the entire
    metrics → PWM computation → serial data transmission loop to a Rust
    backend thread that runs independently of the WebView lifecycle.
    The frontend now only handles UI display (needle/value updates) and
    sends gauge configuration changes to the backend via update_serial_config.
    The backend serial_loop thread reads SharedMetrics, ClaudeCache, and
    ClaudeCodeStats directly, computes gauge percentages, applies EMA
    smoothing, and writes serial data on its own timer.
    Co-Author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
    [lib.rs, serial_loop.rs]
2026-03-11 add: overshoot toggle to allow gauge needle past full-scale mark
    [lib.rs, serial_loop.rs]
2026-03-19 add: "Top" sub-option for Core Utilization and Core Frequency metrics
    Shows the highest value across all cores, useful for spotting single-thread bottlenecks.
2026-03-19 fix: reverse PWM channel index mapping
    [main.rs]
2026-03-19 update: reduce anti-slip sticker edge margin from 6mm to 3mm
    [pointify.scad]
2026-03-19 fix: macOS WKWebView blank screen after window re-appears
    Nudge window size on show and force DOM repaint on both
    visibilitychange and focus events to work around WKWebView
    rendering stall after hide/show or bringing window to front.
    [lib.rs]
2026-03-22 update: 3D enclosure print supports and USB hole fix
    - Add PCB boss print supports (45° ramp on -Y side) to prevent
    collapse when printing face-down
    - Fix USB cutout Z offset from -1.7 to -1.0 to match actual
    connector position
    [pointify.scad]
2026-03-22 add: 8th PWM channel on PC18 (TIM3_CH2)
    Use PC18/DIO debug pin as TIM3_CH2 at remap=2, bringing total PWM channels from 7 to 8 (chip maximum for 20-pin TSSOP).
2026-03-22 update: pcb v2.3 with PWM8
    [pointify.kicad_pcb, pointify.kicad_sch]
2026-03-25 fix: port-cover align
    [pointify.scad]
2026-04-20 fix: poll Claude usage API from backend thread
    Claude API usage stopped updating when the macOS WKWebView blanked out
    because the HTTP fetch was triggered only by the frontend's polling loop.
    Move the fetch into a background thread that refreshes the cache on its
    own TTL, matching how system metrics and Claude Code stats already work.
    [lib.rs]
2026-04-20 fix: reload WebView when JS heartbeat stalls (macOS blank screen)
    After days of idle on macOS, WKWebView's WebContent process can die,
    leaving a fully blank window that focus/visibilitychange forceRepaint
    cannot recover — the JS itself is gone. Frontend now pings the backend
    every 10s and Rust reloads the WebView if no heartbeat arrives for 60s.
    Also add a periodic forceRepaint every 30s as a cheap preventive layer
    for the case where JS is alive but the GPU surface has stalled.
    [lib.rs]
2026-04-20 fix: wrap ClaudeTtl in newtype to avoid Tauri state type collision
    Using Arc<AtomicU64> directly as the ClaudeTtl state type collides with
    SharedInterval (same underlying type) and panics at startup with
    "state for type ... is already being managed". Wrap it in a distinct
    newtype so Tauri's TypeId-keyed registry treats them separately.
    [lib.rs]
2026-04-20 fix: load config for all 8 gauges instead of 7
    The config loader capped its loop at index < 7, so the 8th gauge
    always reverted to the default metric (gpu_clock) on startup even
    when the saved config had a different selection. Save already wrote
    all 8 — only load was wrong. Off-by-one introduced when the 8th PWM
    channel was added.
2026-04-20 feat: configurable rows×cols gauge layout
    Replace single gauge count selector with separate Rows and Cols
    selectors so the UI matches the physical device arrangement. Also
    cap each gauge card at 260px (down from 350px) so they stop growing
    oversized on wide windows. rows*cols is clamped to 8 (hardware limit),
    and the grid's column count updates live. rows and cols are persisted
    in config.json; old configs migrate as 1 × gaugeCount.
    [lib.rs]
2026-04-23 feat: unify Claude metric selector with target sub-options
    Expose new Claude usage buckets (extra_usage, seven_day_omelette as
    "Claude Design", seven_day_sonnet) and collapse Limit/Reset and
    claude_code_* variants into single metrics whose Limit/Reset or
    token/cost target is chosen via the sub-option dropdown.
    [serial_loop.rs]
2026-04-24 feat: replace .claude.env with Credentials modal + multi-account/org
    Move Claude credentials from the plain-text .claude.env file into a
    structured credentials.json managed through an in-app modal (patterned
    after the firmware update modal). Each saved credential expands to all
    claude.ai organizations it has access to, and gauges pick one
    (account × org) pair via a flattened Account dropdown.
    Verified directly against /api/account:
    - capabilities filter: only keep orgs with "chat" capability. API-only
    orgs (console.anthropic.com) appear in memberships but return 403 on
    the usage endpoint.
    - Personal org auto-label: when org.name == "{email}'s Organization",
    show as "(Personal)".
    - P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
    [lib.rs, serial_loop.rs]
2026-05-06 fix: use native WebView reload in heartbeat watchdog
    window.eval("location.reload()") cannot recover the blank screen it
    was meant to fix — when WKWebView's WebContent process has died, the
    JS evaluator is gone with it, so the eval silently no-ops. Switch to
    WebviewWindow::reload(), which dispatches a native -[WKWebView reload]
    that respawns the WebContent process.
    [lib.rs]
2026-05-06 fix: replace window.confirm with two-click arm for account delete
    Tauri 2's WKWebView default delegate makes window.confirm() return
    false immediately and window.alert() a no-op, so clicking Delete in
    the credentials modal silently did nothing. Switch to a two-click
    arm pattern (button toggles to "Confirm?" for 3s) and surface backend
    errors inline on the button instead of via alert().
2026-05-06 fix: respect TTL on Codex usage failures and surface Expired chip
    A stale ~/.codex/auth.json access_token caused the poller to retry
    every 5s and spam the log with "HTTP 401 Unauthorized" because the
    stale check was tied to cache freshness, not attempt time. Track
    last_attempt separately so failures honor the same TTL as successes.
    Dedupe identical error logs and emit a single "recovered" line on
    the next success. Expose the latest error to the WebView via a new
    get_codex_error command and render an "Expired" chip next to the
    Codex section in the credentials modal (with the full error in the
    hover tooltip).
    [lib.rs]
2026-07-20 add: codex server-side plan, workspace list, and duration-based windows
    - Read plan_type from the wham/usage payload (server-fresh) instead of
    relying only on the stale id_token JWT claim, and map all known plan
    values to human-readable labels (unknown values pass through raw)
    - Enumerate accounts/workspaces via wham/accounts/check in the
    credentials modal, marking the active account
    - Send the ChatGPT-Account-Id header on usage fetches like Codex CLI
    - Fix codex_5h/codex_7d gauges assuming primary=5h/secondary=7d: Team
    plans report their weekly credit window as primary_window with no
    short window at all. Select windows by limit_window_seconds and
    compute the Reset sub-metric aga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
    [lib.rs, serial_loop.rs]
2026-07-20 fix: derive app version from Cargo.toml instead of git describe
    CI build jobs now check out a bare sha (shallow, no tags), so git
    describe fell back to the full commit hash and the app displayed it as
    its version, which also broke the update badge comparison against the
    latest release tag.
    The release workflow bumps Cargo.toml to the release version before
    building, so CARGO_PKG_VERSION is the release version — use it with a
    "v" prefix to match release tags, and drop the git invocation from
    build.rs entirely.
    [lib.rs]
2026-11-04 fix: read only the appended lines of Claude Code transcripts
    Every watcher event re-globbed the project dirs and re-parsed each JSONL
    file modified today from the start, so with Claude Code running the
    stats thread re-read everything every couple of seconds.
    Keep a per-file offset and parse only the complete lines appended since
    the last pass. Watcher events now read just the reported files; a full
    scan (still reading only new bytes) runs when the watcher flags dropped
    events or after 30s of quiet. A file that shrank or a date change resets
    the totals and recounts.
2026-11-04 fix: stop the monitor loop from scanning every process each tick
    refresh_all() ran every 200ms and walked every process on the system
    only to report a process count. Drop the Process Count gauge and refresh
    just CPU and memory instead.
    Temperature, network, disk I/O and GPU are now refreshed every tick only
    while an active gauge reads them, and every 10s otherwise so the option
    lists stay populated. Disk capacity is refreshed every 10s regardless:
    on macOS it queries purgeable space, the most expensive call in the loop.
